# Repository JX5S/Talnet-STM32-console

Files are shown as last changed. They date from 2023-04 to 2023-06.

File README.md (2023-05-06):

# Talnet STM32 console
Výuková konzole pro vyučování porgramování v C/C++. Uvnitř je STM32F412RET6 mikroprocesor, barevný LCD displej, inerční jednotka BMI160, pípák, tlačítka a joystick.

Fotografie výsledné konzole Konzole s vytištěnými díly

Elektronika konzole

## Objednávání - plošné spoje
1. Otevřít https://jlcpcb.com/
2. "Add gerber file" a vybrat "GerberA.zip"
3. Změnit "Surface finish" na "LeadFree HASL", pokud nechceme olovo
4. Ostatní nastavení by se měla nastavit podle zip souboru
5. "Save to cart" pro přidání do košíku

6. Opakovat s "GerberB.zip" a objednat

## Objednávání - komponenty z LCSC
1. Otevřít https://lcsc.com/
2. "BOM Tool"
3. Nahrát "LCSC_komponenty.csv"
4. Nad sloupcem množství vybrat v nabídce "Quantity". V souboru jsou sloupce s množstvími pro 1 desku, 5 desek, 10 desek
5. Nad sloupcem "LCSC" vybrat v nabídce "LCSC Part Number"
6. "Next" pro pokračování
7. Zkontrolovat, že je vše na skladě, a kliknout "Add to cart" pro přidání do košíku

8. Pokud něco už není na skladě, je potřeba vybrat náhradní součástky. Většinu součástek by šlo nahradit jednoduše. Dne 30.4.2023 bylo na skladě vše, ale zásoba mikrokontroléru už se krátila - měl by jít nahradit rychlejším, ale dražším STM32F446RET6, bez úpravy desky.
9. Objednat. Pokud první objednáme z JLCPCB, získáme slevu na poštovné

## Objednávání - díly z Aliexpressu
Nabíjecí obvod: https://www.aliexpress.com/item/1005001580997981.html

Displej: https://www.aliexpress.com/item/32843115817.html

BMI160: https://www.aliexpress.com/item/32718555571.html

USB-C: https://www.aliexpress.com/item/1005004598158601.html

## Nastavení programovacího prostředí
1. Stáhneme, nainstalujeme a otevřeme Visual Studio Code
2. V sekci "Extensions" nainstalujeme rozšíření PlatformIO
3. Počkáme na dokončení instalace PlatformIO. Trvá to několik minut
4. File -> Open Folder -> otevřeme nějaký příklad. Měla by být vybrána složka obsahující soubor platformio.ini
5. V sekci "Platformio" otevřeme "Platformio home->Libraries" přidáme do otevřeného projektu knihovnu TFT_eSPI
6. V knihovně (cesta je Příklad/Lib/TFT_eSPI/) zaměníme soubor user_setup.h se souborem z tohoto repositáře. Tento soubor nastaví, jaký konkrétní displej máme. Je možné, že bude nutné mírně upravit pro jiné displeje, i když budou vypadat stejně
7. V sekci "Platformio -> Project tasks" spustíme "Upload" pro nahrání programu

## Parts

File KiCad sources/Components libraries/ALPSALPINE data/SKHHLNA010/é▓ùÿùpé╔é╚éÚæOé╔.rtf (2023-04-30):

ご利用になる前に必ずお読みください。

日頃よりアルプス電気をご愛顧いただきありがとうございます。
ダウンロードいただいたZIPファイルには、2形式のデータが含まれています。

1）STEPファイル
・国際標準フォーマットであるSTEPファイルをご提供しています
・STEPフォーマットに対応した3D CADが必要になります。

2）PDFファイル
・PDFをご覧いただくにはAdobe Reader 8以上が必要になります。
アドビシステムズ社のホームページからダウンロードしてください。
http://www.adobe.com/jp/

・Adobe Acrobat 3D Version 8 以上をお持ちの方は、PDFを標準ファイル
フォーマットであるSTEPやIGESファイルなどに書き出すことができます。

以上

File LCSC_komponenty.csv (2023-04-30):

Qty | 5*QTY | 10*QTY | LCSC
1 | 5 | 10 | C96256
3 | 15 | 30 | C17024
14 | 70 | 140 | C720961
2 | 10 | 20 | C5375882
1 | 5 | 10 | C19110
2 | 10 | 20 | C17024
1 | 5 | 10 | C444721
1 | 5 | 10 | C356987
6 | 30 | 60 | C5301773
1 | 5 | 10 | C492412
1 | 5 | 10 | Aliexpress
1 | 5 | 10 | C2718488
1 | 5 | 10 | C492414
1 | 5 | 10 | C2897388
1 | 5 | 10 | C2988369
1 | 5 | 10 | C5290175
1 | 5 | 10 | C918854
1 | 5 | 10 | C181087
2 | 10 | 20 | C8547
4 | 20 | 40 | C2934153
2 | 10 | 20 | C2907290
8 | 40 | 80 | C2930231
8 | 40 | 80 | C2907295
2 | 10 | 20 | C2930296
2 | 10 | 20 | C2907293
4 | 20 | 40 | C2934173
1 | 5 | 10 | C330583
2 | 10 | 20 | C125031
1 | 5 | 10 | C115348
1 | 5 | 10 | C115348
1 | 5 | 10 | C115348
1 | 5 | 10 | C115348
1 | 5 | 10 | C115348
1 | 5 | 10 | C115348
1 | 5 | 10 | C3020419
1 | 5 | 10 | C89374
1 | 5 | 10 | C150716
1 | 5 | 10 | C94021
1 | 5 | 10 | C13740
1 | 5 | 10 | C14730

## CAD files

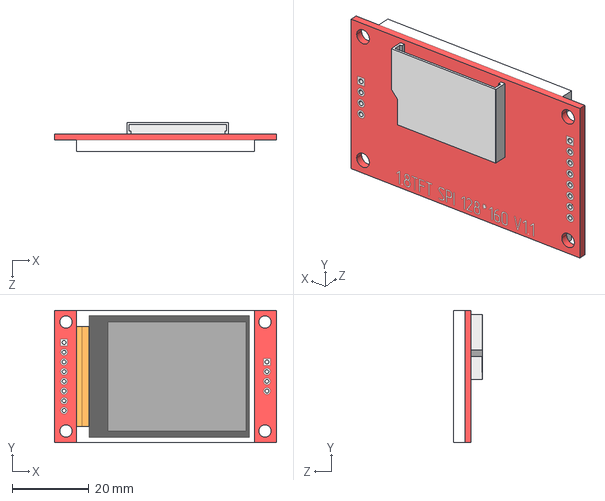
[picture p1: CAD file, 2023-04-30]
KiCad sources/Components libraries/1.8 TFT 128x160 SPI.STEP
58.0 x 34.5 x 7.60 mm

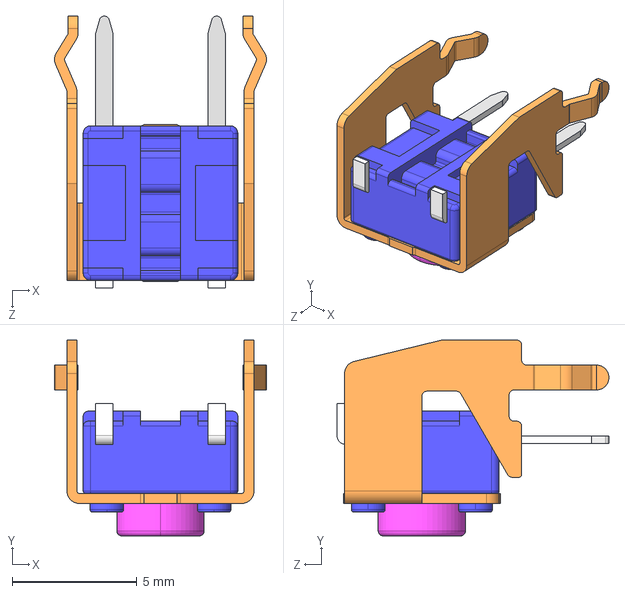
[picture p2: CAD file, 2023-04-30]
KiCad sources/Components libraries/ALPSALPINE data/SKHHLNA010/SKHHLN.STEP
8.50 x 7.85 x 10.9 mm

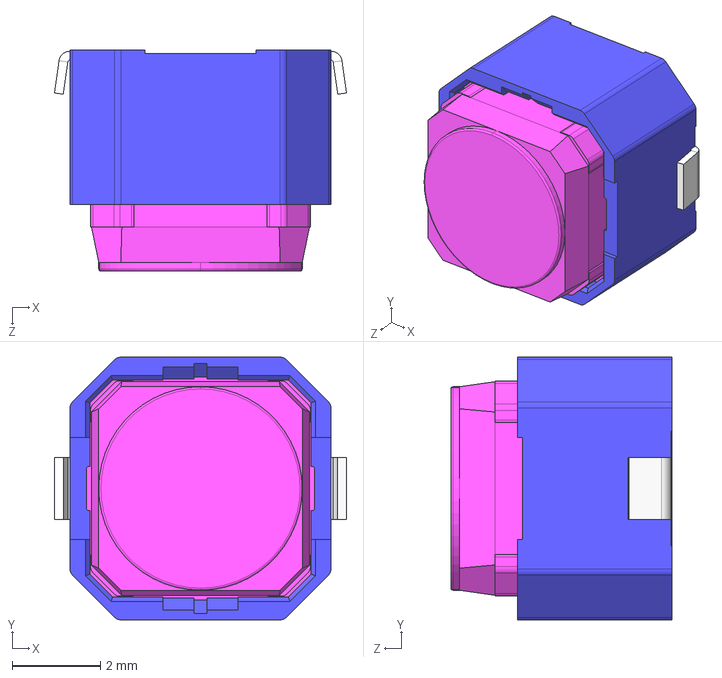
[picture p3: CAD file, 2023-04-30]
KiCad sources/Components libraries/ALPSALPINE data/SKPMAME010/SKPMAM.STEP
6.60 x 5.94 x 5.00 mm

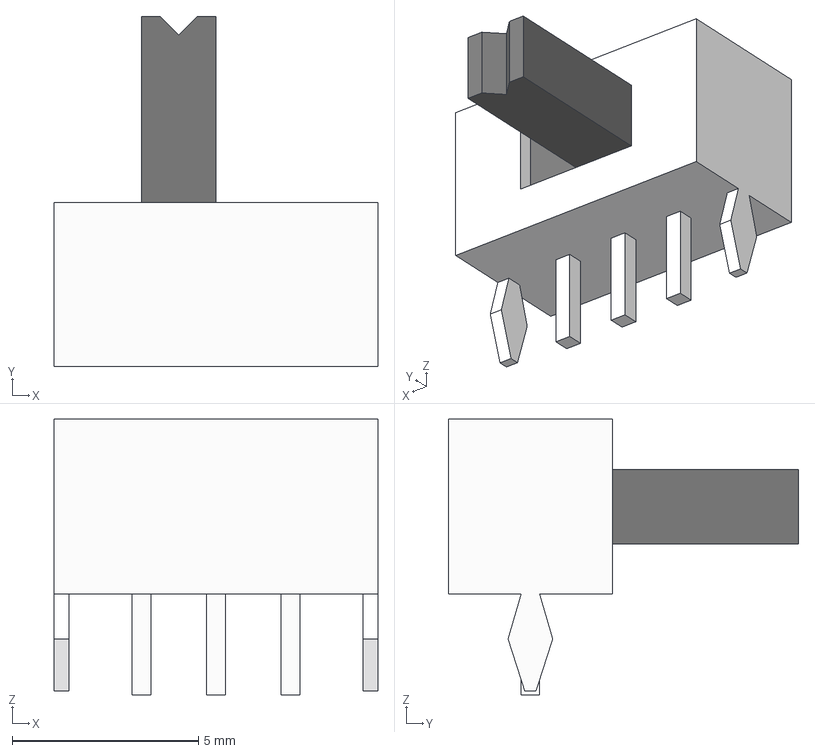
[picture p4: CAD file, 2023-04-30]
KiCad sources/Components libraries/Moje 3D/Slide switch v1.step
8.70 x 9.40 x 7.40 mm

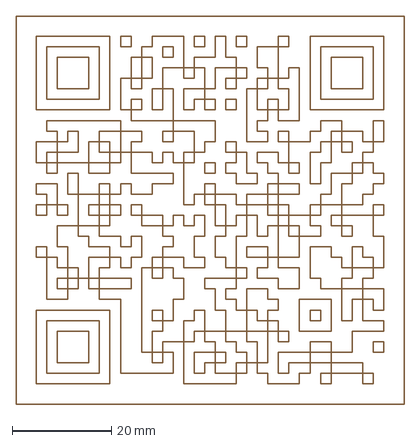
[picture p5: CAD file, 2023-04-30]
KiCad sources/QR.dxf
78.0 x 78.0 mm

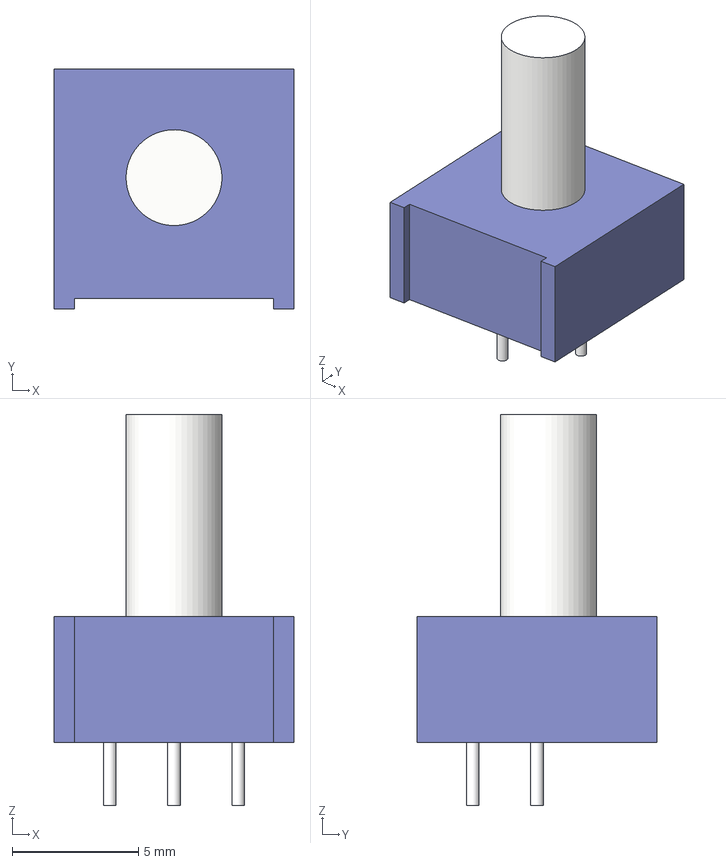
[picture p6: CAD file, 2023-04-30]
KiCad sources/Components libraries/Moje 3D/Potenciometr Bochen v1.step
9.50 x 9.50 x 15.5 mm

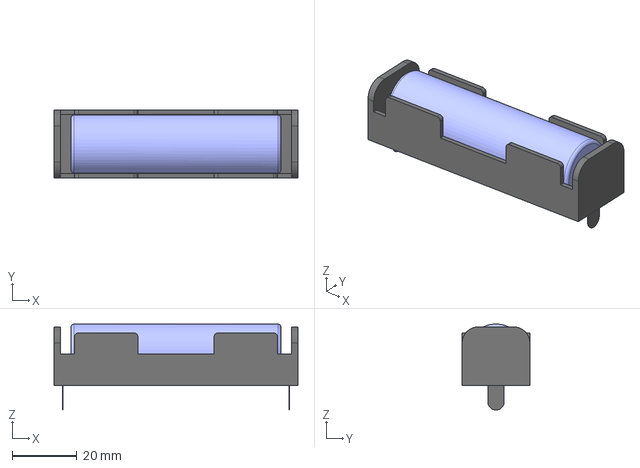
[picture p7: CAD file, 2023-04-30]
KiCad sources/Components libraries/Moje 3D/18650 holder MYOUNG v1.step
75.5 x 21.0 x 26.6 mm

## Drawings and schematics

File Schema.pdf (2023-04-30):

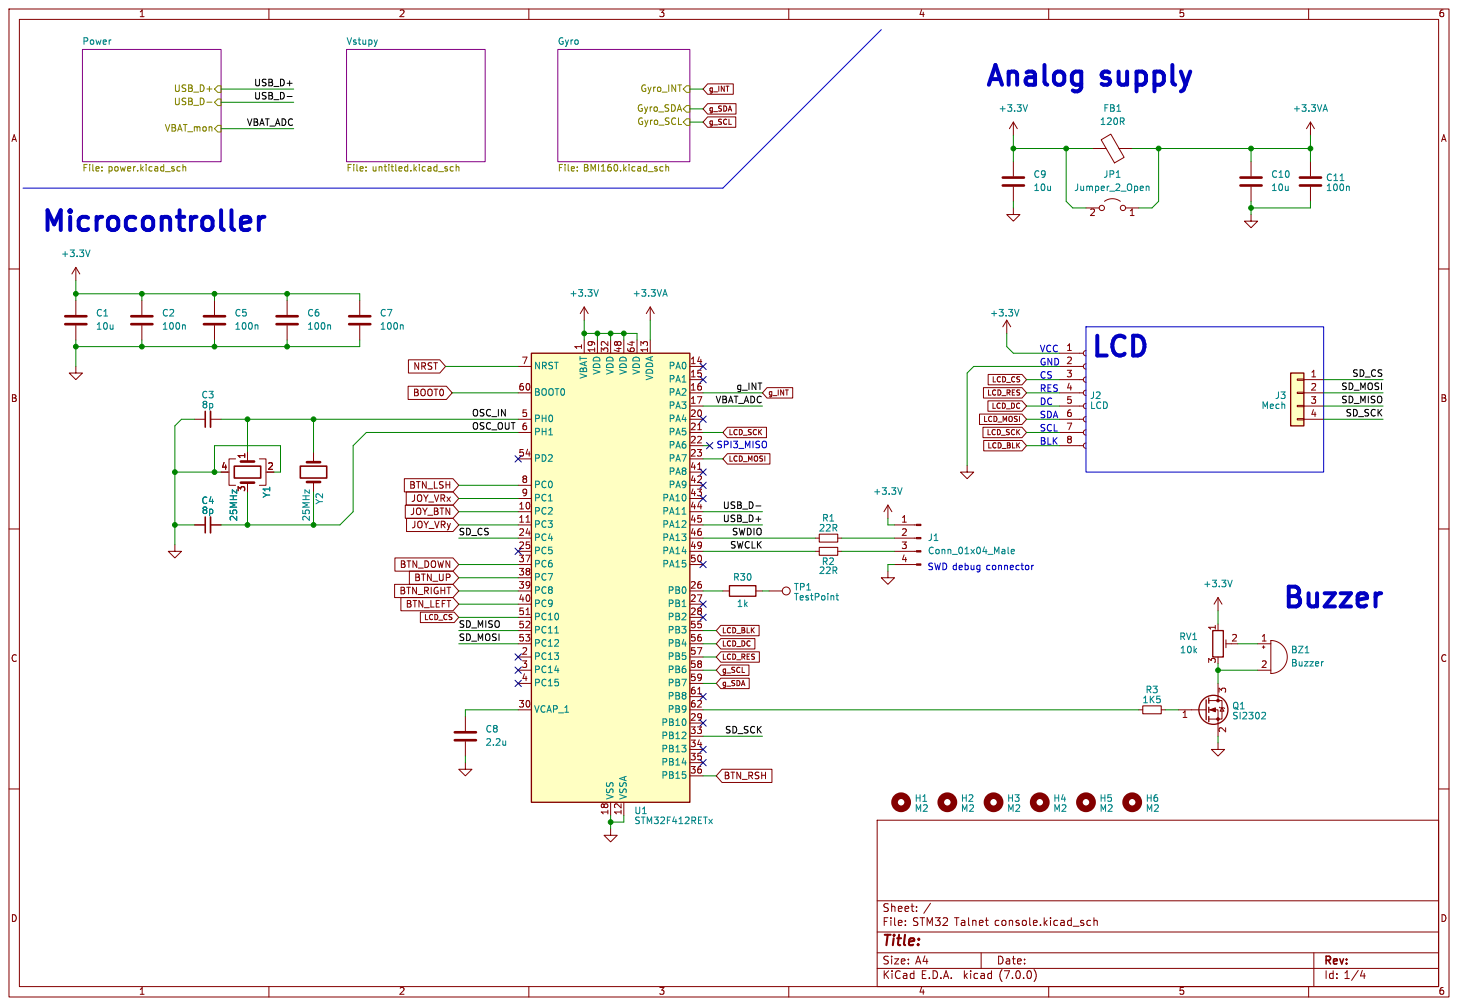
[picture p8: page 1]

Gyro File: BMI160.kicad_sch Vstupy File: untitled.kicad_sch USB_D- USB_D+ VBAT_mon Power File: power.kicad_sch

SWD debug connector Analog supply

1 PC2 10 PC3 11 VSSA 12 VDDA 13 PA0 14 PA1 15 PA2 16 PA3 17 VSS 18 VDD 19 PC13 2 PA4 20 PA5 21 PA6 22 PA7 23 PC4 24 PC5 25 PB0 26 PB1 27 PB2 28 PB10 29 PC14 3 VCAP_1 30 VDD 32 PB12 33 PB13 34 PB14 35 PB15 36 PC6 37 PC7 38 PC8 39 PC15 4 PC9 40 PA8 41 PA9 42 PA10 43 PA11 44 PA12 45 PA13 46 VDD 48 PA14 49 PH0 5 PA15 50 PC10 51 PC11 52 PC12 53 PD2 54 PB3 55 PB4 56 PB5 57 PB6 58 PB7 59 PH1 6 BOOT0 60 PB8 61 PB9 62 VDD 64 NRST 7 PC0 8 PC1 9 U1STM32F412RETx

Id: 1/4 Title: File: STM32 Talnet console.kicad_sch Sheet: /

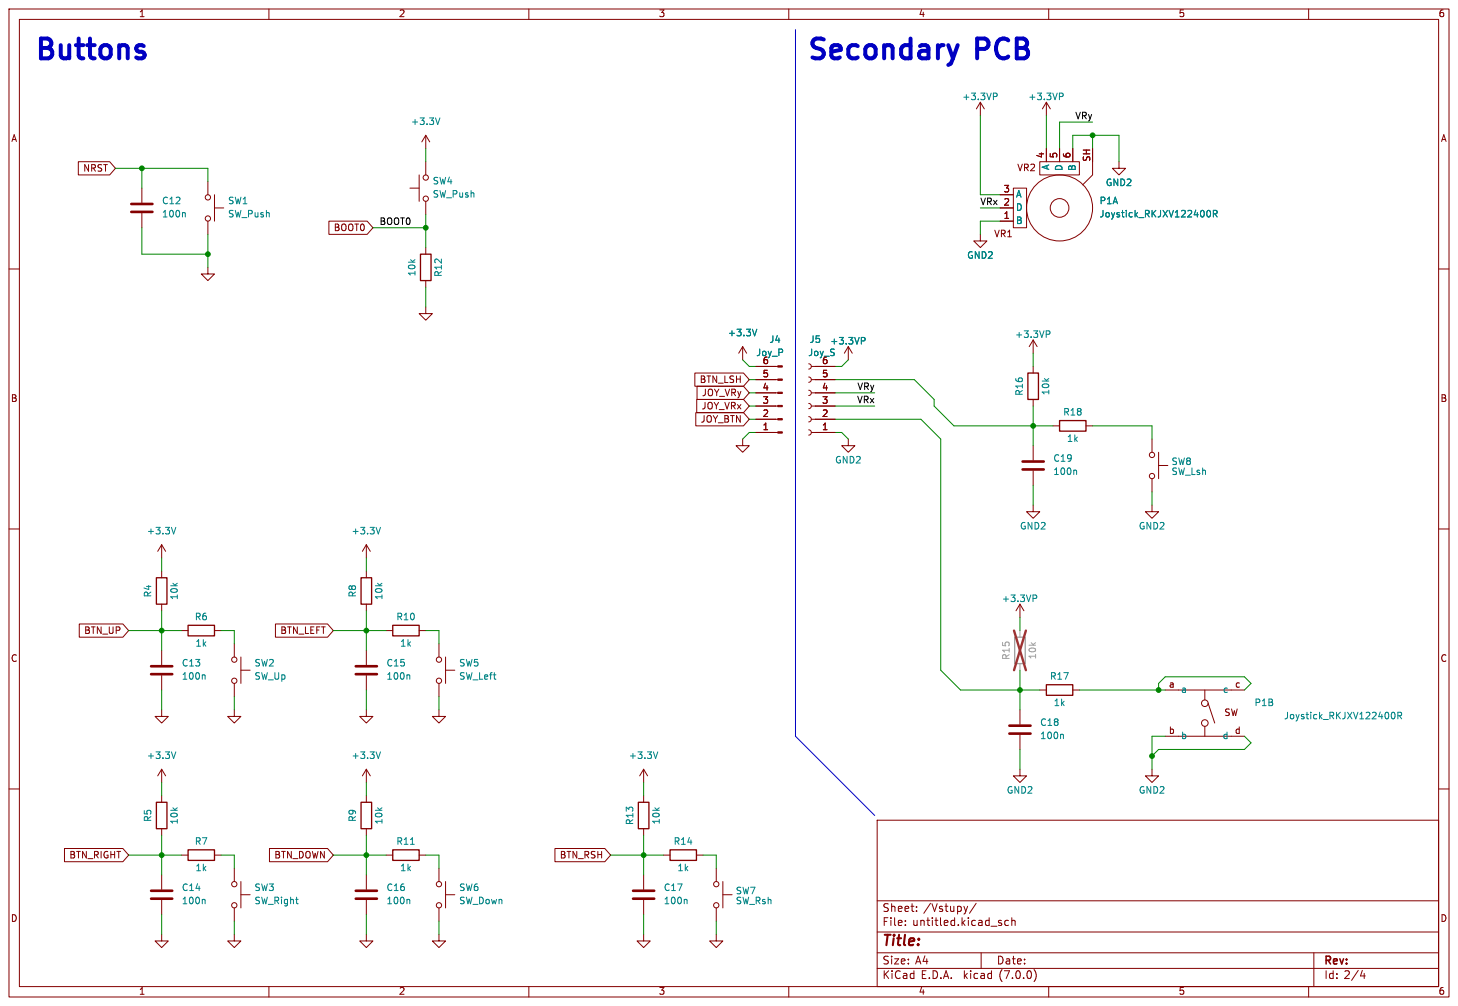
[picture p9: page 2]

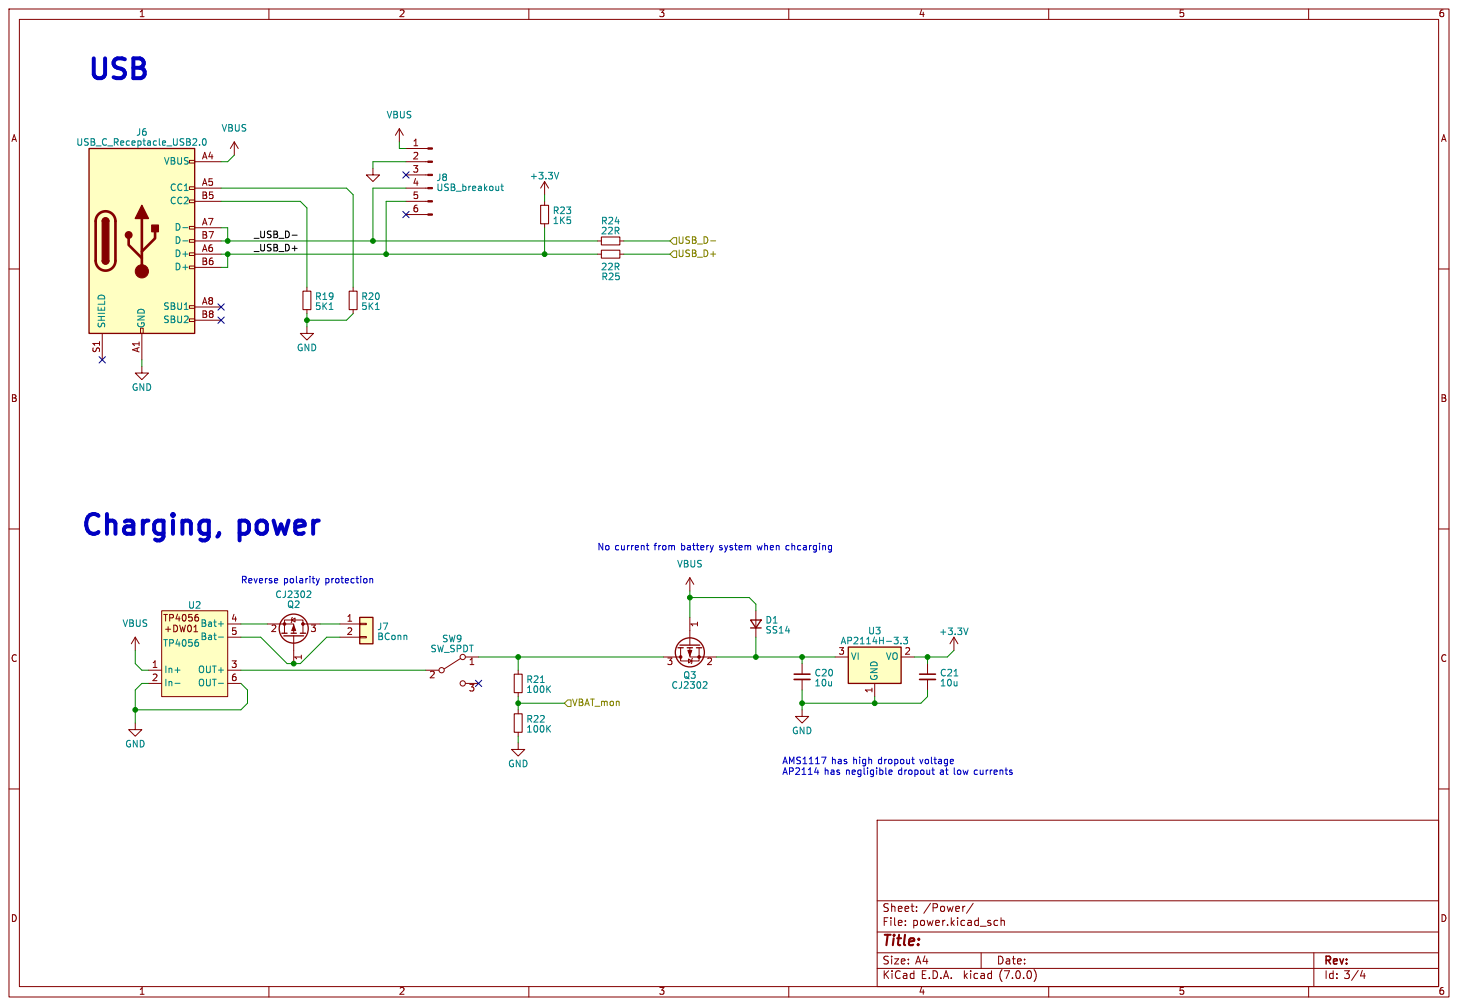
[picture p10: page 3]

Id: 3/4 Title: File: power.kicad_sch Sheet: /Power/ 1

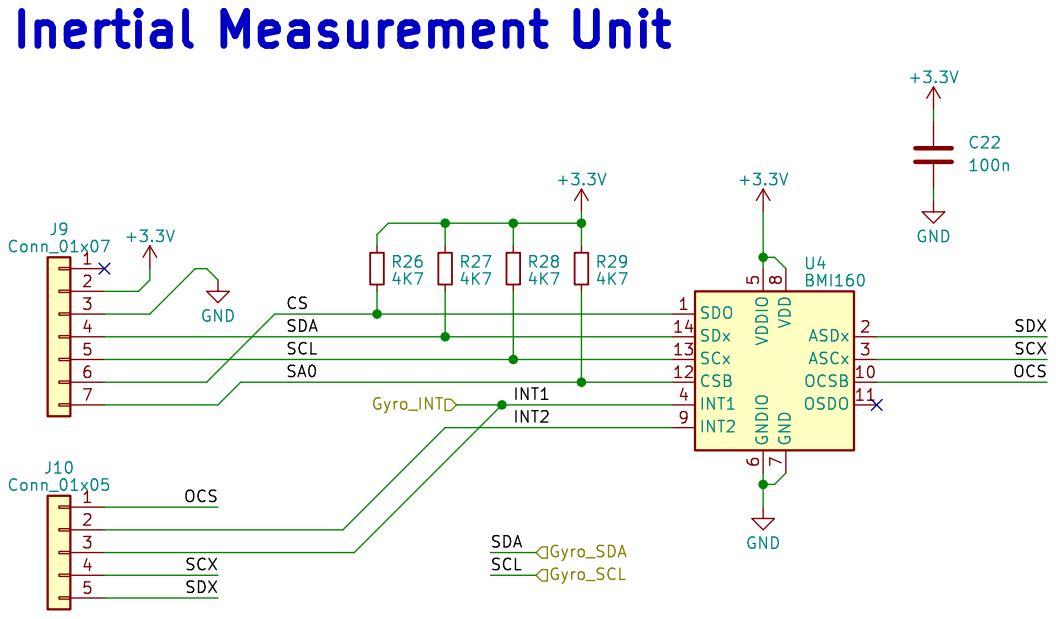
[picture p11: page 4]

Id: 4/4 Title: File: BMI160.kicad_sch Sheet: /Gyro/

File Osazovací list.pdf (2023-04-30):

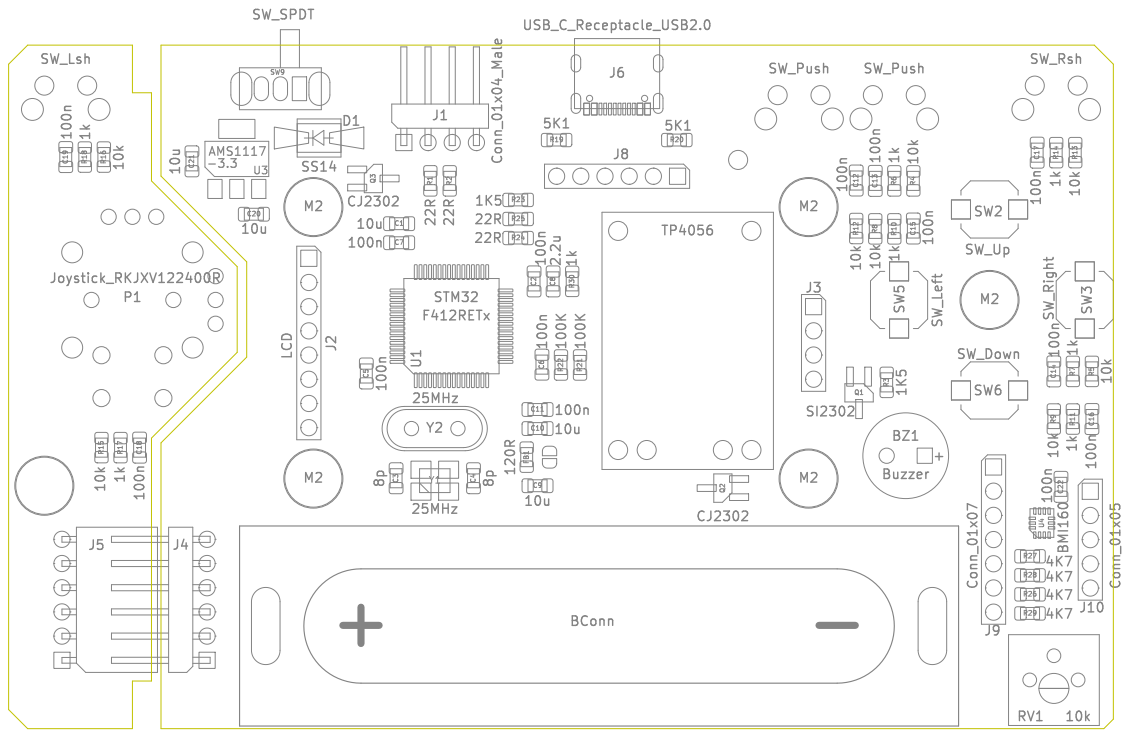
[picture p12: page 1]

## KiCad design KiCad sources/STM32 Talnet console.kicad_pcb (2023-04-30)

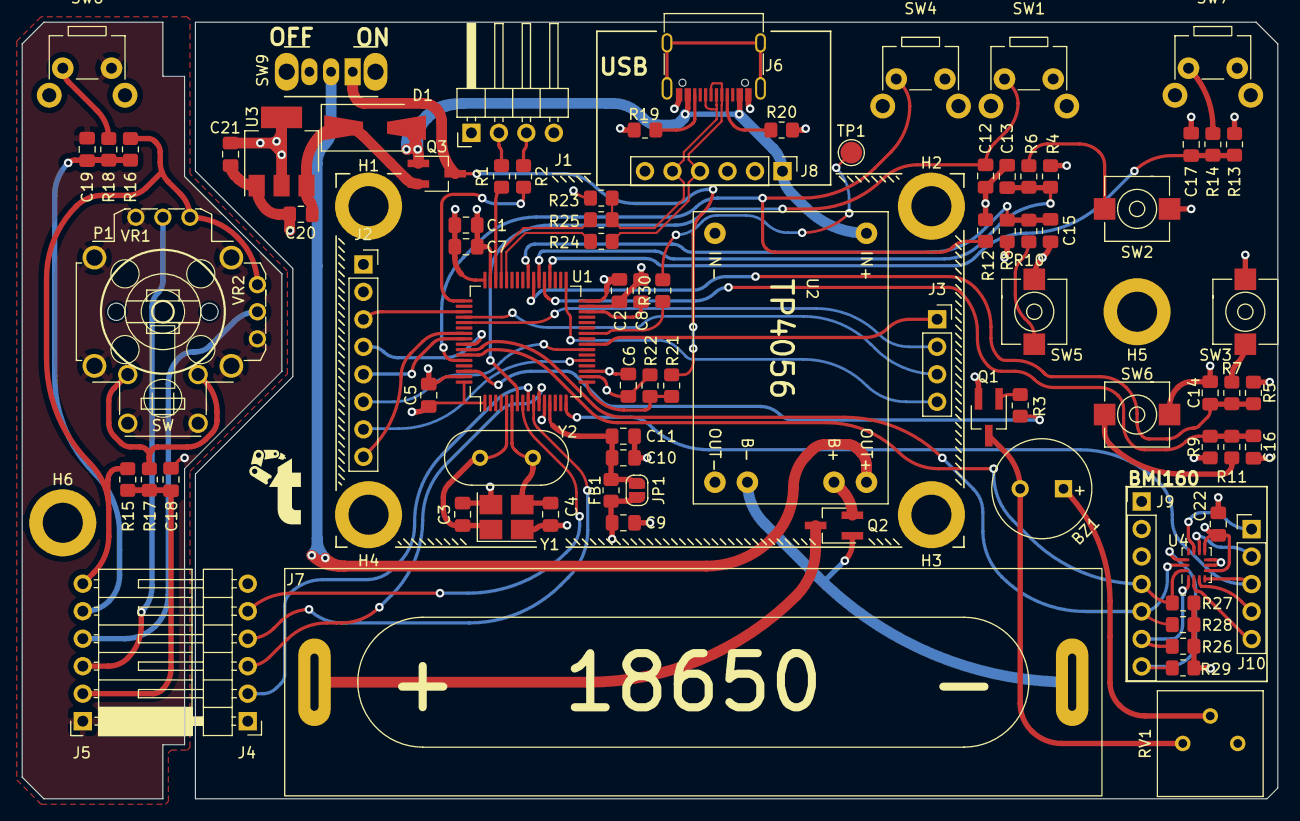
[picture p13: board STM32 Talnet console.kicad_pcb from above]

Board: 4 copper layers, 116.0 x 71.8 mm, 93 parts (0 on the bottom side), 65 nets.

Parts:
BZ1: Buzzer; MagneticBuzzer_PUI_AT-0927-TT-6-R
C1, C9, C10, C20, C21: 10u; C_0805_2012Metric_Pad1.18x1.45mm_HandSolder
C2, C5, C6, C7, C11, C12, C13, C14, C15, C16, C17, C18, C19, C22: 100n; C_0805_2012Metric_Pad1.18x1.45mm_HandSolder
C3, C4: 8p; C_0805_2012Metric_Pad1.18x1.45mm_HandSolder
C8: 2.2u; C_0805_2012Metric_Pad1.18x1.45mm_HandSolder
D1: SS14; D_SMA-SMB_Universal_Handsoldering
FB1: 120R; R_0805_2012Metric_Pad1.20x1.40mm_HandSolder
H1, H2, H3, H4, H5, H6: M2; M2 solder nut
J1: Conn_01x04_Male; PinHeader_1x04_P2.54mm_Horizontal
J2: LCD; PinSocket_1x08_P2.54mm_Vertical
J3: Mech; PinSocket_1x04_P2.54mm_Vertical
J4: Joy_P; PinHeader_1x06_P2.54mm_Horizontal
J5: Joy_S; PinSocket_1x06_P2.54mm_Horizontal
J6: USB_C_Receptacle_USB2.0; USB_C_Receptacle_G-Switch_GT-USB-7010ASV
J7: BConn; 18650 MYOUNG
J8: USB_breakout; PinHeader_1x06_P2.54mm_Vertical
J9: Conn_01x07; PinHeader_1x07_P2.54mm_Vertical
J10: Conn_01x05; PinHeader_1x05_P2.54mm_Vertical
JP1: Jumper_2_Open; SolderJumper-2_P1.3mm_Open_RoundedPad1.0x1.5mm
P1: Joystick_RKJXV122400R; Joystic_ALPSALPINE_RKJXV122400D
Q1: SI2302; SOT-23W_Handsoldering
Q2, Q3: CJ2302; SOT-23W_Handsoldering
R1, R2, R24, R25: 22R; R_0805_2012Metric_Pad1.20x1.40mm_HandSolder
R3, R23: 1K5; R_0805_2012Metric_Pad1.20x1.40mm_HandSolder
R4, R5, R8, R9, R12, R13, R15, R16: 10k; R_0805_2012Metric_Pad1.20x1.40mm_HandSolder
R6, R7, R10, R11, R14, R17, R18, R30: 1k; R_0805_2012Metric_Pad1.20x1.40mm_HandSolder
R19, R20: 5K1; R_0805_2012Metric_Pad1.20x1.40mm_HandSolder
R21, R22: 100K; R_0805_2012Metric_Pad1.20x1.40mm_HandSolder
R26, R27, R28, R29: 4K7; R_0805_2012Metric_Pad1.20x1.40mm_HandSolder
RV1: 10k; Potentiometer_Bourns_3386P_Vertical
SW1, SW4: SW_Push; SKHHLNA010
SW2: SW_Up; Switch_ALPSALPINE_SKPMAME010
SW3: SW_Right; Switch_ALPSALPINE_SKPMAME010
SW5: SW_Left; Switch_ALPSALPINE_SKPMAME010
SW6: SW_Down; Switch_ALPSALPINE_SKPMAME010
SW7: SW_Rsh; SKHHLNA010
SW8: SW_Lsh; SKHHLNA010
SW9: SW_SPDT; SW_CuK_OS102011MA1QN1_SPDT_Angled
TP1: TestPoint; TestPoint_Pad_D2.0mm
U1: STM32F412RETx; LQFP-64_10x10mm_P0.5mm
U2: TP4056; TP4056+prot
U3: AMS1117-3.3; SOT-223-3_TabPin2
U4: BMI160; Bosch_LGA-14_3x2.5mm_P0.5mm
Y1: 25MHz; Crystal_SMD_3225-4Pin_3.2x2.5mm_HandSoldering
Y2: 25MHz; Crystal_HC49-4H_Vertical

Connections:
+3.3V: C1.1, C2.1, C5.1, C6.1, C7.1, C9.1, C21.1, C22.1, FB1.2, J1.1, J2.1, J4.6, J9.2, JP1.2 (B), R4.2, R5.2, R8.2, R9.2, R13.2, R23.1, R26.1, R27.1, R28.1, R29.1, RV1.1, SW4.2, U1.1 (VBAT), U1.19 (VDD), U1.32 (VDD), U1.48 (VDD), U1.64 (VDD), U3.2 (VO), U4.5 (VDDIO), U4.8 (VDD)
+3.3VA: C10.1, C11.1, FB1.1, JP1.1 (A), U1.13 (VDDA)
+3.3VP: J5.6, P1.3 (A), P1.4 (A), R15.2, R16.2
/Gyro/CS: J9.6, R26.2, U4.1 (SDO)
/Gyro/INT2: J10.2, U4.9 (INT2)
/Gyro/OCS: J10.1, U4.10 (OCSB)
/Gyro/SA0: J9.7, R29.2, U4.12 (CSB)
/Gyro/SCX: J10.4, U4.3 (ASCx)
/Gyro/SDX: J10.5, U4.2 (ASDx)
/OSC_IN: C3.2, U1.5 (PH0), Y1.1, Y2.1
/OSC_OUT: C4.2, U1.6 (PH1), Y1.3, Y2.2
/Power/_USB_D+: J6.A6 (D+), J6.B6 (D+), J8.5, R23.2, R25.1
/Power/_USB_D-: J6.A7 (D-), J6.B7 (D-), J8.4, R24.2
/SD_CS: J3.1, U1.24 (PC4)
/SD_MISO: J3.3, U1.52 (PC11)
/SD_MOSI: J3.2, U1.53 (PC12)
/SD_SCK: J3.4, U1.33 (PB12)
/SWCLK: R2.1, U1.49 (PA14)
/SWDIO: R1.2, U1.46 (PA13)
/USB_D+: R25.2, U1.45 (PA12)
/USB_D-: R24.1, U1.44 (PA11)
/VBAT_ADC: R21.2, R22.1, U1.17 (PA3)
/Vstupy/VRx: J5.3, P1.2 (D)
/Vstupy/VRy: J5.4, P1.5 (D)
BOOT0: R12.1, SW4.1, U1.60 (BOOT0)
BTN_DOWN: R9.1, U1.37 (PC6)
BTN_LEFT: R8.1, U1.40 (PC9)
BTN_RIGHT: R5.1, U1.39 (PC8)
BTN_UP: R4.1, U1.38 (PC7)
GND: C1.2, C2.2, C3.1, C4.1, C5.2, C6.2, C7.2, C8.2, C9.2, C10.2, C11.2, C12.2, C13.2, C14.2, C15.2, C16.2, C17.2, C20.2, C21.2, C22.2, J1.4, J2.2, J4.1, J6.A1 (GND), J6.A12 (GND), J6.B1 (GND), J6.B12 (GND), J8.2, J9.3, Q1.2 (S), R12.2, R19.2, R20.2, R22.2, SW1.2, SW2.2, SW3.2, SW5.2, SW6.2, SW7.2, U1.12 (VSSA), U1.18 (VSS), U1.31 (VSS), U1.47 (VSS), U1.63 (VSS), U2.2 (In-), U2.6 (OUT-), U3.1 (GND), U4.6 (GNDIO), U4.7 (GND), Y1.2, Y1.4
GND2: C18.2, C19.2, J5.1, P1.1 (B), P1.6 (B), P1.SH, P1.b, P1.d, SW8.2
LCD_BLK: J2.8, U1.55 (PB3)
LCD_CS: J2.3, U1.51 (PC10)
LCD_DC: J2.5, U1.56 (PB4)
LCD_MOSI: J2.6, U1.23 (PA7)
LCD_RES: J2.4, U1.57 (PB5)
LCD_SCK: J2.7, U1.21 (PA5)
NRST: C12.1, SW1.1, U1.7 (NRST)
unnamed: BZ1.2 (+), Q1.3 (D), RV1.3
unnamed: BZ1.1 (-), RV1.2
unnamed: C20.1, D1.1 (K), Q3.2 (S), U3.3 (VI)
unnamed: J1.2, R1.1
unnamed: J1.3, R2.2
unnamed: C18.1, J5.2, R15.1, R17.1
unnamed: C19.1, J5.5, R16.1, R18.1
unnamed: J6.A5 (CC1), R20.1
unnamed: J6.B5 (CC2), R19.1
unnamed: J7.1, Q2.3 (D)
unnamed: J7.2, Q2.1 (G), U2.5 (Bat-)
unnamed: P1.a, P1.c, R17.2
unnamed: Q1.1 (G), R3.2
unnamed: Q2.2 (S), U2.4 (Bat+)
unnamed: Q3.3 (D), R21.1, SW9.1 (A)
unnamed: R6.2, SW2.1
unnamed: R7.2, SW3.1
unnamed: R10.2, SW5.1
unnamed: R11.2, SW6.1
unnamed: R14.2, SW7.1
unnamed: R18.2, SW8.1
unnamed: R30.2, TP1.1
unnamed: SW9.2 (B), U2.3 (OUT+)
unnamed: R30.1, U1.26 (PB0)
unnamed: R3.1, U1.62 (PB9)
unnamed: C8.1, U1.30 (VCAP_1)
VBUS: D1.2 (A), J6.A4 (VBUS), J6.A9 (VBUS), J6.B4 (VBUS), J6.B9 (VBUS), J8.1, Q3.1 (G), U2.1 (In+)

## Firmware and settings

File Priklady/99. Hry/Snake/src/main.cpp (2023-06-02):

#include <TFT_eSPI.h>
#include <SPI.h>
#include "console.h"
#include "graphics.h"

TFT_eSPI tft = TFT_eSPI();
TFT_eSprite frame_buffer = TFT_eSprite(&tft);

void upbtn();
void downbtn();
void leftbtn();
void rightbtn();
void end();

void setup(void) {
  pinMode(PB0, OUTPUT); // pro debug - je to ploška uvnitř konzole, není zvenku dostupná
  pinMode(PB3, OUTPUT);
  analogWrite(Console_TFT_BLK, 255);

  pinMode(Console_BTN_Up, INPUT);
  pinMode(Console_BTN_Down, INPUT);
  pinMode(Console_BTN_Left, INPUT);
  pinMode(Console_BTN_Right, INPUT);
  
  attachInterrupt(Console_BTN_Up, upbtn, FALLING);
  attachInterrupt(Console_BTN_Down, downbtn, FALLING);
  attachInterrupt(Console_BTN_Left, leftbtn, FALLING);
  attachInterrupt(Console_BTN_Right, rightbtn, FALLING);

  tft.init();
  tft.setRotation(3);
  tft.fillScreen(BLACK);

  frame_buffer.createSprite(160, 128);
  frame_buffer.fillRect(20,20,160,128,TFT_BLUE);
}

uint8_t snak_dir = 1; // snake head direction. Changes in interrupts
uint8_t cur_snak_dir = snak_dir; // copied value to prevent being changed during calculating tick

uint8_t apple_x = 3; // apple coordinates
uint8_t apple_y = 3;
uint8_t was_apple = 0; // if an apple was eaten last tick, show tile of snake that has eaten an apple

uint16_t len = 1; // snake length. 1=just head
uint8_t addlen = 0;

uint8_t isSnak[200] = { 0 }; // array of whether tile contains a snake or not, used for collision and apple spawning

int8_t body_xcord[200] = {5, 0 }; // coordinates of snake body parts
int8_t body_ycord[200] = {5, 0 };
uint8_t body_dirs[200] = { 0 }; // directions of snake body parts
uint8_t body_pic[200] = {1, 0 }; // 0 apple, 1-4 head, 5-8 tail, 9-10 straight, 11-12 straight W/apple, 13-16 bent, 17-20 bent W/apply

static const unsigned short* graphics[21] = {apple, Head0, Head1, Head2, Head3, Tail0, Tail1, Tail2, Tail3, Straight0, Straight1, Straight_apple0, Straight_apple1, Bent01, Bent12, Bent23, Bent03, Bent_apple01, Bent_apple12, Bent_apple23, Bent_apple03};

void loop() {
  // evaluate buttons
  if(digitalRead(Console_BTN_Up)+digitalRead(Console_BTN_Down)+digitalRead(Console_BTN_Left)+digitalRead(Console_BTN_Right) == 3){
    if (!digitalRead(Console_BTN_Up) && cur_snak_dir != 2) snak_dir = 0;
    if (!digitalRead(Console_BTN_Down) && cur_snak_dir != 0) snak_dir = 2;
    if (!digitalRead(Console_BTN_Left) && cur_snak_dir != 1) snak_dir = 3;
    if (!digitalRead(Console_BTN_Right) && cur_snak_dir != 3) snak_dir = 1;
  }
  
  cur_snak_dir = snak_dir; // copy so value doesn't change during code
  
  isSnak[body_xcord[len-1]+20*body_ycord[len-1]] = 0;  // tail of last tick no longer contains snake

  // move snake forward
  for (int i = len-1; i >= 1; i--){
    body_xcord[i] = body_xcord[i-1];
    body_ycord[i] = body_ycord[i-1];
    body_pic[i] = body_pic[i-1];
    body_dirs[i] = body_dirs[i-1];
  }
  
  body_dirs[0] = cur_snak_dir;
  
  // determining which tile the one after the head should be
  if(len>1){
    if(body_dirs[0] == body_dirs[1]){ // if both the first tile and head tile have the same direction, it is straight
      body_pic[1] = 9 + body_dirs[1]%2 + 2*was_apple; // 9 - offset for straight tile
    } else { // bent tile
      switch(((body_dirs[0]+2)%4+1)*(body_dirs[1]+1)){ // needed a comutative operation to check which sides of the bent tile should be connected
        case 12:
          body_pic[1] = 13 + 4*was_apple;
          break;
        case 4:
          body_pic[1] = 14 + 4*was_apple;
          break;
        case 2:
          body_pic[1] = 15 + 4*was_apple;
          break;
        case 6:
          body_pic[1] = 16 + 4*was_apple;
          break;
      }
    }
    body_pic[len-1] = 5 + body_dirs[len-2]; // tail
  }
  switch(cur_snak_dir) // move snake
  {
    case 0:
      body_ycord[0] -= 1;
      if(body_ycord[0]<0) end(); // check for out of bounds
      break;
    case 1:
      body_xcord[0] += 1;
      if(body_xcord[0]>=20) end();
      break;
    case 2:
      body_ycord[0] += 1;
      if(body_ycord[0]>=10) end();
      break;
    case 3:
      body_xcord[0] -= 1;
      if(body_xcord[0]<0) end();
      break;
  }

  if(isSnak[body_xcord[0]+20*body_ycord[0]]){ // check for collision with snake
    end();
  } else {
    isSnak[body_xcord[0]+20*body_ycord[0]] = 1; // mark head position as snake
  }

  was_apple = 0;
  if(body_xcord[0] == apple_x && body_ycord[0] == apple_y){
    addlen = 1;
    was_apple = 1;
    while(isSnak[apple_x+20*apple_y]){
      apple_x = random(20);
      apple_y = random(10);
    }
  }

  //drawing:
  frame_buffer.fillRect(0,0,160,24,0x34AD);
  frame_buffer.fillRect(0,24,160,80, 0x6DE6);
  frame_buffer.fillRect(0,104,160,24,0x34AD);
 
  frame_buffer.setSwapBytes(true); // endianness
  for (int i = 1; i < len; i++){ // for each body part draw corresponding picture. Except head
        frame_buffer.pushImage(body_xcord[i] * 8,body_ycord[i]*8+24,8,8,graphics[body_pic[i]]);
  }

  // draw head
  frame_buffer.pushImage(body_xcord[0]*8, body_ycord[0]*8+24, 8, 8, graphics[1 + (cur_snak_dir+2)%4]);

  // draw apple
  frame_buffer.pushImage(apple_x * 8, apple_y * 8 + 24, 8, 8, apple);

  // actually push out to the screen
  frame_buffer.pushSprite(0,0);

  if(addlen){
    len++;
    addlen = 0;
  }

  delay(200);
  HAL_GPIO_TogglePin(GPIOB, GPIO_PIN_0);
}

void end(){
  tft.fillRect(0,0,160,128,TFT_RED);
  tft.setTextDatum(CC_DATUM);
  tft.setTextSize(2);
  tft.drawString("Konec",80,50);
  tft.drawString("Delka: " + String(len),80,78);
  while(true);
}

// interrupts should be as short as possible
void upbtn(){
  if(cur_snak_dir != 2) snak_dir = 0;
}
void downbtn(){
  if(cur_snak_dir != 0) snak_dir = 2;
}
void leftbtn(){
  if(cur_snak_dir != 1) snak_dir = 3;
}
void rightbtn(){
  if(cur_snak_dir != 3) snak_dir = 1;
}

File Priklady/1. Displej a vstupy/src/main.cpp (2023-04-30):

#include <Arduino.h>
#include "console.h"
#include <SPI.h>
#include "TFT_eSPI.h"

TFT_eSPI tft = TFT_eSPI();

void setup() {
  // put your setup code here, to run once:
  pinMode(Console_BTN_Up, INPUT);
  pinMode(Console_BTN_Down, INPUT);
  pinMode(Console_BTN_Left, INPUT);
  pinMode(Console_BTN_Right, INPUT);
  pinMode(Console_BTN_LShoulder, INPUT);
  pinMode(Console_BTN_RShoulder, INPUT);
  pinMode(Console_Joy_BTN, INPUT);
  pinMode(Console_Joy_X, INPUT);
  pinMode(Console_Joy_Y, INPUT);
  
  tft.init();

  tft.setRotation(3);

  tft.fillScreen(TFT_BLACK);

  pinMode(Console_TFT_BLK, OUTPUT);
  analogWrite(Console_TFT_BLK, 255); // jas podsvícení
}

void loop() {
  // put your main code here, to run repeatedly:
  tft.fillScreen(TFT_BLACK);
  tft.setCursor(0,0);
  tft.println("X: " + String(analogRead(Console_Joy_X)));
  tft.println("Y: " + String(analogRead(Console_Joy_Y)));
  
  tft.drawRect(109,0,51,51, TFT_PURPLE);
  tft.fillCircle(109 + analogRead(Console_Joy_X)/20, 0 + (1024-analogRead(Console_Joy_Y))/20, 3, TFT_GREEN);

  if(!digitalRead(Console_BTN_Up)){
    tft.println("Nahoru");
  }
  if(!digitalRead(Console_BTN_Down)){
    tft.println("Dolu");
  }
  if(!digitalRead(Console_BTN_Left)){
    tft.println("Doleva");
  }
  if(!digitalRead(Console_BTN_Right)){
    tft.println("Doprava");
  }
  if(!digitalRead(Console_BTN_LShoulder)){
    tft.println("Leve-rameno");
  }
  if(!digitalRead(Console_BTN_RShoulder)){
    tft.println("Prave-rameno");
  }
  if(!digitalRead(Console_Joy_BTN)){
    tft.println("Jostick-tlacitko");
  }
  tft.drawTriangle(100,100,120,110,100,126,TFT_YELLOW);
  tft.fillCircle(150, 110, 5, TFT_RED);
  tft.fillRectHGradient(0,90,90,20,TFT_GOLD, TFT_BLUE);
  delay(100);
}

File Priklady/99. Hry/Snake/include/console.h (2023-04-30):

#define Console_LED           PB0

#define Console_Buzzer        PB9

#define Console_BTN_RShoulder PB15
#define Console_BTN_LShoulder PC0
#define Console_BTN_Left      PC9
#define Console_BTN_Right     PC8
#define Console_BTN_Up        PC7
#define Console_BTN_Down      PC6

#define Console_Joy_BTN       PC1
#define Console_Joy_X         PC3
#define Console_Joy_Y         PC2

#define Console_TFT_BLK       PB3
#define Console_TFT_MISO      PC11
#define Console_TFT_MOSI      PC12
#define Console_TFT_SCK       PB12
#define Console_TFT_CS        PC10
#define Console_TFT_RST       PB5
#define Console_TFT_DC        PB4
